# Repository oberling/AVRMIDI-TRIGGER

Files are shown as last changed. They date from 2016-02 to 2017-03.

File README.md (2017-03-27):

AVRMIDI-TRIGGER
==========

This is an implementation of a simple MIDI to Trigger converter using a Atmel Attiny2313 microprocessor. Each Note-On Event in a given MIDI Note Range is converted into a Trigger Signal of 5 V.

The current Note Range is 8 Notes from middle C (MIDI-Channel 5 - see Makefile for more info).
I was able to reuse a lot of sourcecode from my AVR MIDI-CV converter here... which is nice.

It also supports multitrigger/flames via velocity: there are 16 pre-defined flame pattern and velocity of 127 gives you a simple trigger.

If you want to see the MIDI to Trigger converter in action (also hearing the flame pattern): [video of the SDSV clone i built](https://www.youtube.com/watch?v=ALU4drFba9A)

Schematic
=========

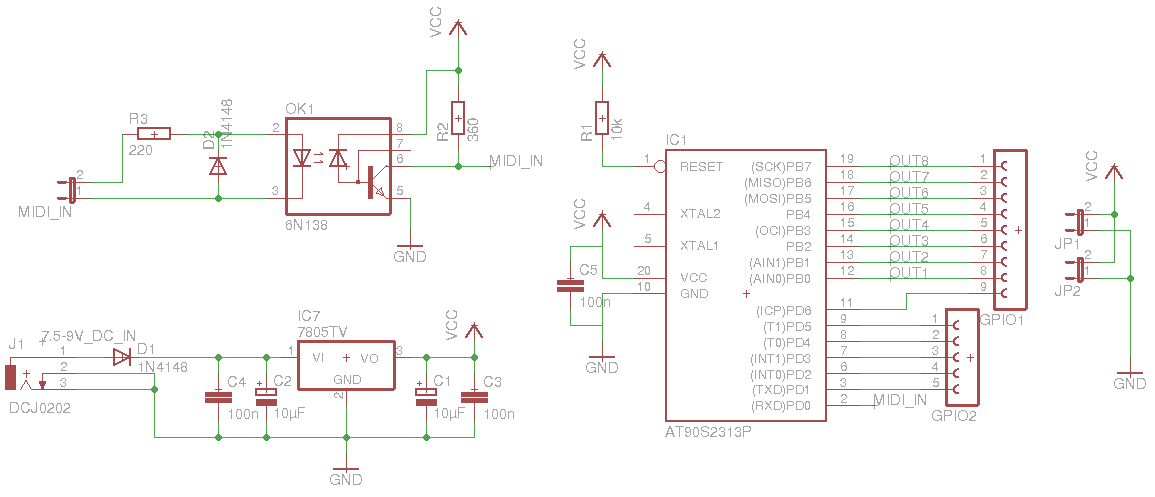
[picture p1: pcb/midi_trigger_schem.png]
schematic picture


Teststatus
==========

complete.

The code has been tested with my SDS5 clone and works fine.
The code has been tested with an oscilloscope and seems to work fine.

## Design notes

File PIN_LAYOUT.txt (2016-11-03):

ATtiny2313
PB0		-	TRIGGER Output 1
PB1		-	TRIGGER Output 2
PB2		-	TRIGGER Output 3
PB3		-	TRIGGER Output 4
PB4		-	TRIGGER Output 5
PB5		-	TRIGGER Output 6
PB6		-	TRIGGER Output 7
PB6		-	TRIGGER Output 8
PD0		-	RXD		(MIDI-IN)

fusebitsettings:
-U lfuse:w:0xe4:m -U hfuse:w:0xdf:m -U efuse:w:0xff:m 
... that is 8MHz internal RC Osc (without internal clock division)

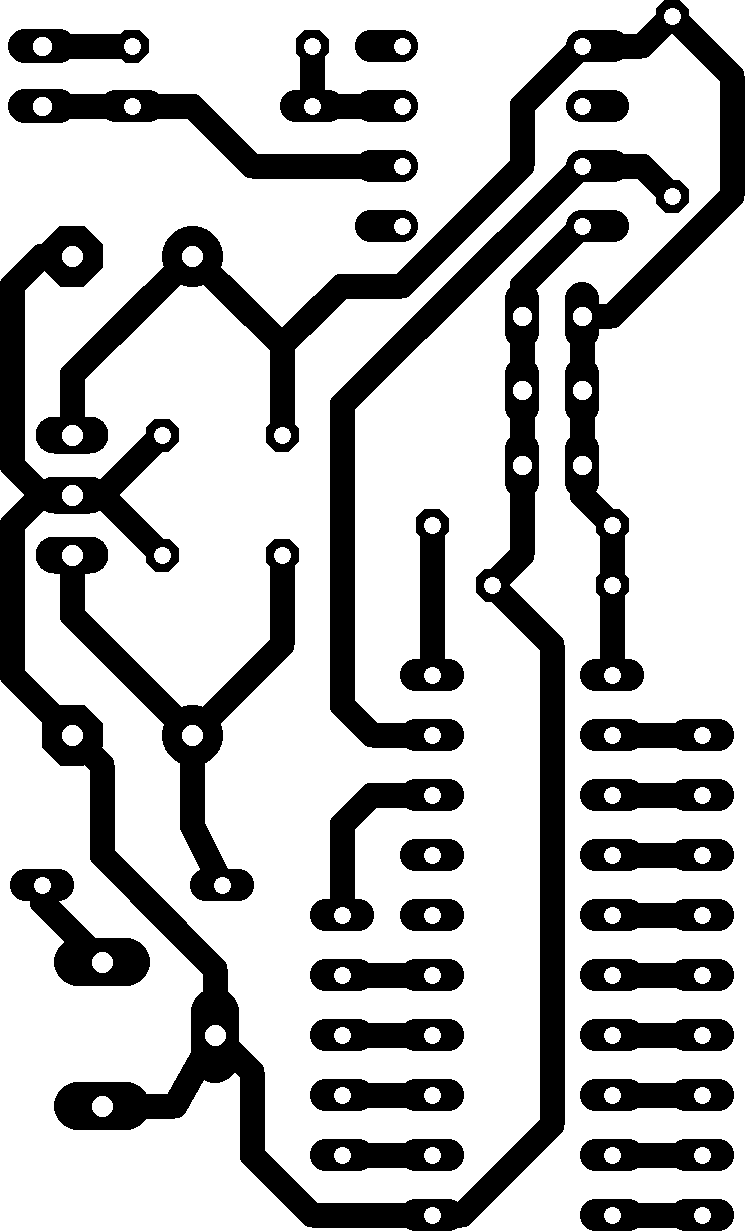
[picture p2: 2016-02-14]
pcb/midi_trigger_pcb.png

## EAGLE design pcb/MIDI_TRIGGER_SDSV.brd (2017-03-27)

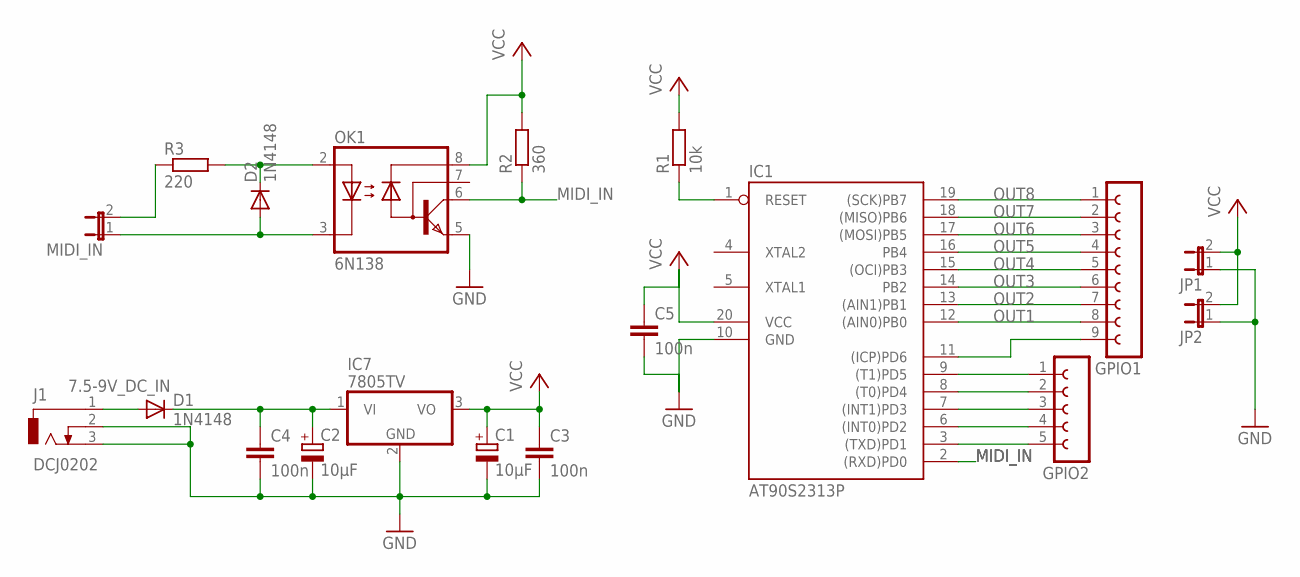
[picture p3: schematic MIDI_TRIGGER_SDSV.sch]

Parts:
C1, C2: 10µF; E5-8,5
C3, C4, C5: 100n; C050-025X075
D1, D2: 1N4148; DO35-7
GPIO1: FE09-1; FE09
GPIO2: FE05-1
IC1: AT90S2313P; DIL20
IC7: 7805TV; TO220V
J1: DCJ0202
JP1, JP2: JP1E; JP1
MIDI_IN: JP1E; JP1
OK1: 6N138; DIL08
R1: 10k; 0204/7
R2: 360; 0204/7
R3: 220; 0204/7

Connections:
7.5-9V_DC_IN: D1.A, J1.1
GND: C1.-, C2.-, C3.2, C4.2, C5.2, IC1.10 (GND), IC7.2 (GND), J1.2, J1.3, JP1.1, JP2.1, OK1.5 (GND)
MIDI_IN: IC1.2 ((RXD)PD0), OK1.6 (VO), R2.1
unnamed: GPIO1.9, IC1.11 ((ICP)PD6)
unnamed: GPIO2.1, IC1.9 ((T1)PD5)
unnamed: GPIO2.2, IC1.8 ((T0)PD4)
unnamed: C2.+, C4.1, D1.C, IC7.1 (VI)
unnamed: GPIO2.3, IC1.7 ((INT1)PD3)
unnamed: GPIO2.4, IC1.6 ((INT0)PD2)
unnamed: GPIO2.5, IC1.3 ((TXD)PD1)
unnamed: IC1.1 (RESET), R1.1
unnamed: MIDI_IN.2, R3.1
unnamed: D2.C, OK1.2 (A), R3.2
unnamed: D2.A, MIDI_IN.1, OK1.3 (C)
OUT1: GPIO1.8, IC1.12 ((AIN0)PB0)
OUT2: GPIO1.7, IC1.13 ((AIN1)PB1)
OUT3: GPIO1.6, IC1.14 (PB2)
OUT4: GPIO1.5, IC1.15 ((OCI)PB3)
OUT5: GPIO1.4, IC1.16 (PB4)
OUT6: GPIO1.3, IC1.17 ((MOSI)PB5)
OUT7: GPIO1.2, IC1.18 ((MISO)PB6)
OUT8: GPIO1.1, IC1.19 ((SCK)PB7)
VCC: C1.+, C3.1, C5.1, IC1.20 (VCC), IC7.3 (VO), JP1.2, JP2.2, OK1.8 (VCC), R1.2, R2.2

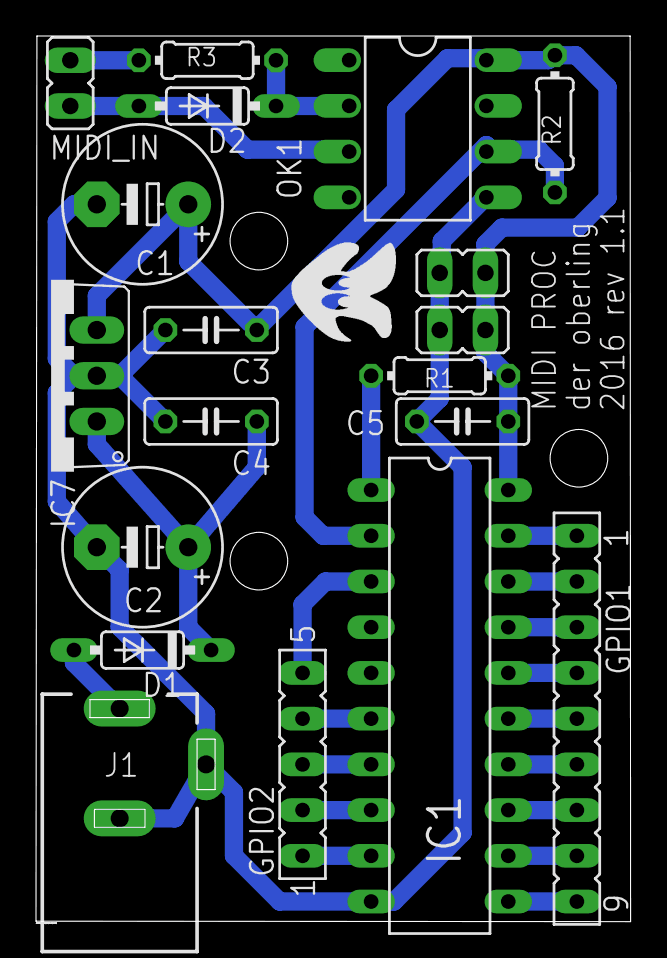
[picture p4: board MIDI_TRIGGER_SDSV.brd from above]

Board: 2 copper layers, 33.0 x 49.2 mm, 19 parts (0 on the bottom side), 23 nets.

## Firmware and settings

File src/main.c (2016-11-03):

#include "uart.h"
#include "midi_datatypes.h"
#include "midibuffer.h"
#include "trigger_flame.h"
#include <avr/io.h>
#include <avr/interrupt.h>
#include <avr/pgmspace.h>
#include <stdint.h>
#include <stdbool.h>

#define TRIGGER_PORT	PORTB
#define TRIGGER_DDR		DDRB
#define TRIGGER1		PB0
#define TRIGGER2		PB1
#define TRIGGER3		PB2
#define TRIGGER4		PB3
#define TRIGGER5		PB4
#define TRIGGER6		PB5
#define TRIGGER7		PB6
#define TRIGGER8		PB7
#define TRIGGER_PIN_OFFSET	0
#define NUM_TRIGGER_OUTPUTS		8
#ifndef TRIGGER_COUNTER_INIT
#pragma message "TRIGGER_COUTNER_INIT not defined - defaulting to 20"
#define TRIGGER_COUNTER_INIT	20
#endif
#ifndef MIDI_NOTE_OFFSET
#pragma message "MIDI_NOTE_OFFSET not defined - defaulting to 60"
// 60 is the middle C
#define MIDI_NOTE_OFFSET	60
#endif
#ifndef MIDI_CHANNEL
#pragma message "MIDI_CHANNEL not defined - defaulting to 5"
// MIDI_CHANNEL is off by 1 (begins at 0 but shown as 1)
#define MIDI_CHANNEL 4
#endif

#define TRIGGER_FLAME_PRESCALER	4

midibuffer_t midi_buffer;
uint8_t midi_channel = MIDI_CHANNEL;
uint8_t trigger_flame_counter = TRIGGER_FLAME_PRESCALER;

trigger_output_t trigger_output[NUM_TRIGGER_OUTPUTS];
bool must_update_trigger_output = false;

bool must_update_flames = false;

bool midi_handler_function(midimessage_t* m);
void update_trigger_output(void);
void update_flames(void);
void init_trigger_outputs(void);
void init_io(void);
void init_variables(void);

bool midi_handler_function(midimessage_t* m) {
	// only return true if something of interest happened
	if(m->byte[0] == NOTE_ON(midi_channel) && m->byte[2] != 0) { // Velocity must not be 0
		if(m->byte[1]>=MIDI_NOTE_OFFSET && m->byte[1]<(MIDI_NOTE_OFFSET+NUM_TRIGGER_OUTPUTS)) { // if in range of triggering notes
			trigger_output[m->byte[1]-MIDI_NOTE_OFFSET].output_counter = TRIGGER_COUNTER_INIT;
			// use velocity for flame selection - 127 being the normal single trigger
			uint8_t flame_type = m->byte[2]>>3; // simple scale down division by 8
			trigger_output[m->byte[1]-MIDI_NOTE_OFFSET].flame_type = flame_type;
			trigger_output[m->byte[1]-MIDI_NOTE_OFFSET].flame_sequence_position = 0;
			trigger_output[m->byte[1]-MIDI_NOTE_OFFSET].flame_sequence_counter = pgm_read_byte(&(trigger_flame[flame_type][0]));
			return true;
		}
	}
	return false;
}

void update_trigger_output(void) {
	// only change output status - no decrement of counters here!
	uint8_t i=0;
	for(;i<NUM_TRIGGER_OUTPUTS;i++) {
		if(trigger_output[i].output_counter) {
			TRIGGER_PORT |= (1<<(TRIGGER_PIN_OFFSET+i));
		} else {
			TRIGGER_PORT &= ~(1<<(TRIGGER_PIN_OFFSET+i));
		}
	}
}

void update_flames(void) {
	uint8_t i=0;
	for(;i<NUM_TRIGGER_OUTPUTS;i++) {
		if(trigger_output[i].flame_sequence_counter) {
			// count down our current sequence counter
			trigger_output[i].flame_sequence_counter -= 1;
			// current sequence step is over - see if there are remaining steps
			if(
				trigger_output[i].flame_sequence_counter == 0 &&
				trigger_output[i].flame_sequence_position < NUM_FLAME_STEPS-1 && 
				pgm_read_byte(&(trigger_flame[trigger_output[i].flame_type][trigger_output[i].flame_sequence_position+1]))
			) {
					// initiate next step of sequence - trigger the output
					trigger_output[i].flame_sequence_position += 1;
					trigger_output[i].flame_sequence_counter = pgm_read_byte(&(trigger_flame[trigger_output[i].flame_type][trigger_output[i].flame_sequence_position]));
					trigger_output[i].output_counter = TRIGGER_COUNTER_INIT;
					must_update_trigger_output = true;
			}
		}
	}
}

void init_trigger_outputs(void) {
	uint8_t i=0;
	for(;i<NUM_TRIGGER_OUTPUTS;i++) {
		trigger_output[i].output_counter = 0;
		trigger_output[i].flame_sequence_position = 0;
		trigger_output[i].flame_sequence_counter = 0;
		trigger_output[i].flame_type = 0;
	}
}

void init_io(void) {
	TRIGGER_DDR |= (1<<TRIGGER1)|(1<<TRIGGER2)|(1<<TRIGGER3)|(1<<TRIGGER4)|(1<<TRIGGER5)|(1<<TRIGGER6)|(1<<TRIGGER7)|(1<<TRIGGER8);
	TCCR0B = (1<<CS01); // at 8000000Hz/8 = 1000000Hz -> 1000000Hz/256 = 3906.25Hz -> 1/3906.25Hz = 256µs
	TIMSK |= (1<<TOIE0);
	uart_init();
}

void init_variables(void) {
	midibuffer_init(&midi_buffer, &midi_handler_function);
	init_trigger_outputs();
}

ISR(TIMER0_OVF_vect) {
	// decrement counters here - trigger update of outputs if trigger is over
	uint8_t i=0;
	for(;i<NUM_TRIGGER_OUTPUTS;i++) {
		if(trigger_output[i].output_counter) {
			trigger_output[i].output_counter -= 1;
			if(trigger_output[i].output_counter == 0) {
				must_update_trigger_output = true;
			}
		}
	}
	trigger_flame_counter++;
	if(trigger_flame_counter > TRIGGER_FLAME_PRESCALER) {
		trigger_flame_counter = 0;
		must_update_flames = true;
	}
}

ISR(USART_RX_vect) {
	char a;
	uart_getc(&a);
	// this method only affects the writing position in the midibuffer
	// therefor it's ISR-save as long as the buffer does not run out of
	// space!!! prepare your buffers, everyone!
	midibuffer_put(&midi_buffer, a);
}

int main(int argc, char** argv) {
	cli();
	init_variables();
	init_io();
	sei();
	while(true) {
		// handle midi data prefered - always handle all midi messages first
		while(midibuffer_tick(&midi_buffer)) {
			must_update_trigger_output = true;
		}
		if(must_update_trigger_output) {
			must_update_trigger_output = false;
			update_trigger_output();
		}
		if(must_update_flames) {
			// could be done in the interrupt routine as well but has too many instructions
			must_update_flames = false;
			update_flames();
		}
	}
	return 0;
}

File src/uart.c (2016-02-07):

#include "uart.h"

void uart_init(void) {
	UBRRH = UBRR_VAL >> 8;
	UBRRL = UBRR_VAL & 0xFF;
	
	UCSRB |= (1<<TXEN);							// enable UART TX
#if defined(__AVR_ATmega8__)
	UCSRC  = (1<<URSEL)|(1<<UCSZ1)|(1<<UCSZ0);  // asynchronous 8N1
#elif defined(__AVR_ATtiny2313__)
	UCSRC  = (1<<UCSZ1)|(1<<UCSZ0);  // asynchronous 8N1
#endif
	UCSRB |= (1<<RXEN);							// enable UART RX
	UCSRB |= (1<<RXCIE);
}

bool uart_putc(unsigned char c) {
	while(!(UCSRA & (1<<UDRE)));
	UDR = c;
	return true;
}

bool uart_puts(char* s) {
	while(*s) {
		uart_putc(*s);
		s++;
	}
	return true;
}

bool uart_getc(char* out) {
	while(!(UCSRA & (1<<RXC)));
	*out = UDR;
	return true;
}

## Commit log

2016-02-07 added fusebitsettings
2016-02-14 added (generic) pcb and schematic
    [MIDI_TRIGGER_SDSV.brd, MIDI_TRIGGER_SDSV.sch]
2016-02-14 also added easy printable pcb png for home etching
2017-03-27 updated schematic and added picture of schematic for non-eagle users
    [MIDI_TRIGGER_SDSV.brd, MIDI_TRIGGER_SDSV.sch]
